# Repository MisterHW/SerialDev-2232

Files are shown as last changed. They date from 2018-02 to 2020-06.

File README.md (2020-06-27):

## SerialDev-2232 ##
The SerialDev-2232 board is a 50 x 50 mm² prototyping PCB with a FTDI FT2232HQ USB interface IC, 12 MHz oscillator and 3.3V, 1.2V LDOs. 

It breaks out the two Multi-Protocol Synchronous Serial Engine (MPSSE) ports, one particularly labeled as a JTAG / SPI / UART port, the other one as a full 16 I/O interface including the 8 bit parallel 245 type FIFO / bit banging interface.

Half of the PCB is dedicated to 5V, 3.3V, 1.2V supplies, 12 MHz clock source and a fully implemented FT2232H with EEPROM, all of which also feed into a linear header (cut the PCB in half for breadboard depolyment). The rest is just 0.1" perf board. 

### assembled PCB ###
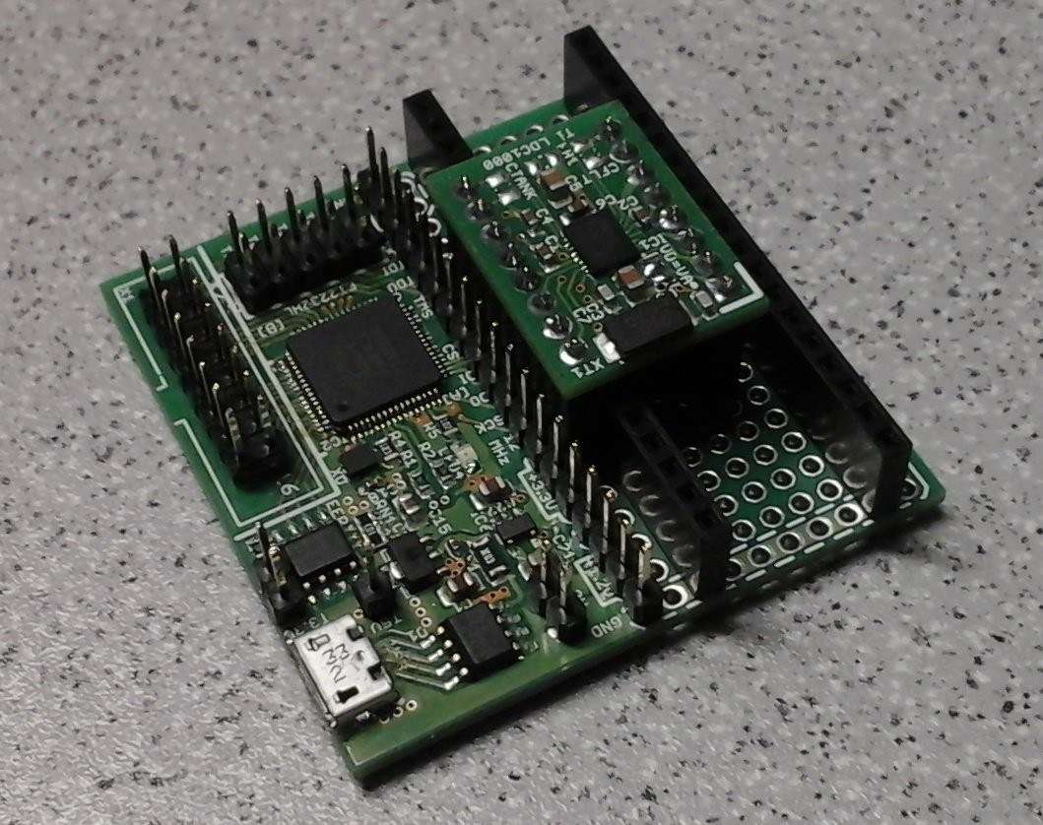
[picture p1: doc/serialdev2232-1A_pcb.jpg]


### schematic ###

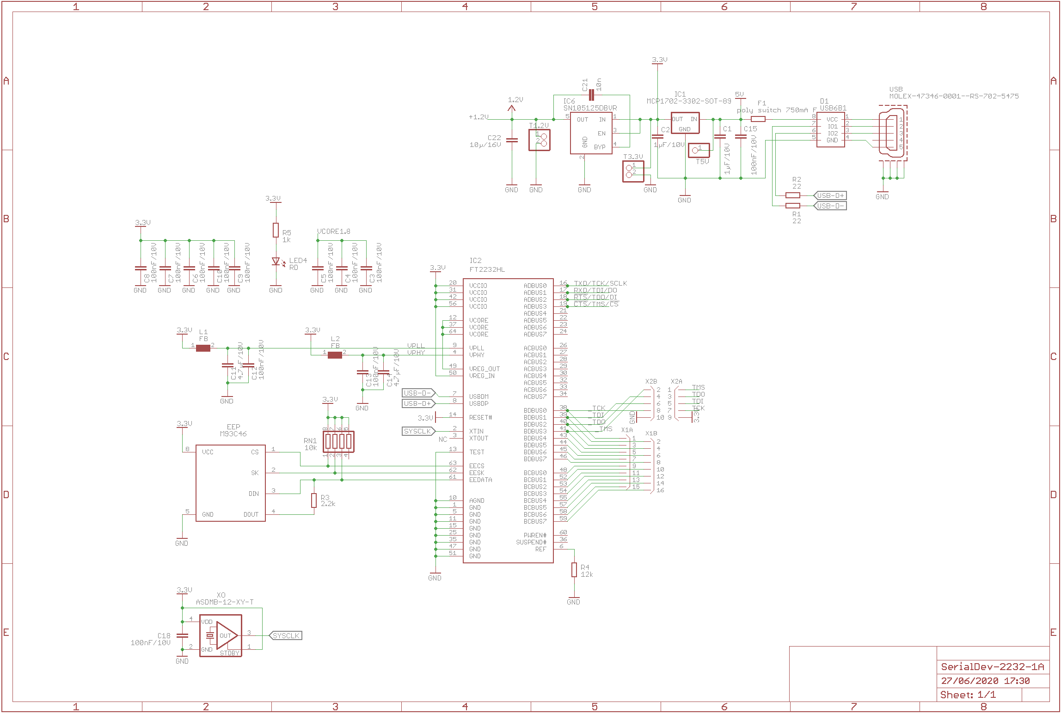
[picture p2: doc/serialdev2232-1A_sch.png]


### layout ###

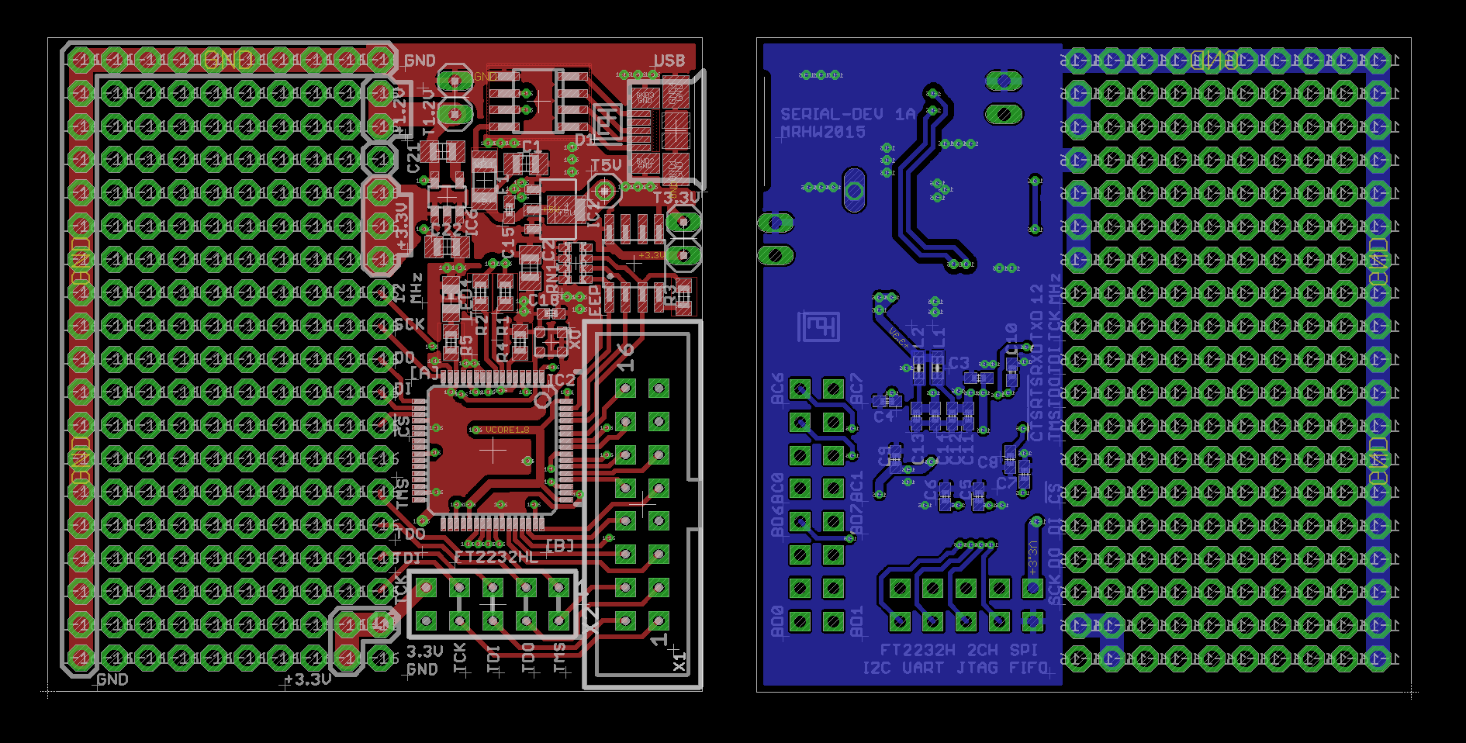
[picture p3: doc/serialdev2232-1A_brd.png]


### further information ###

For more please also check out https://hackaday.io/project/9902-serial-dev-2232.

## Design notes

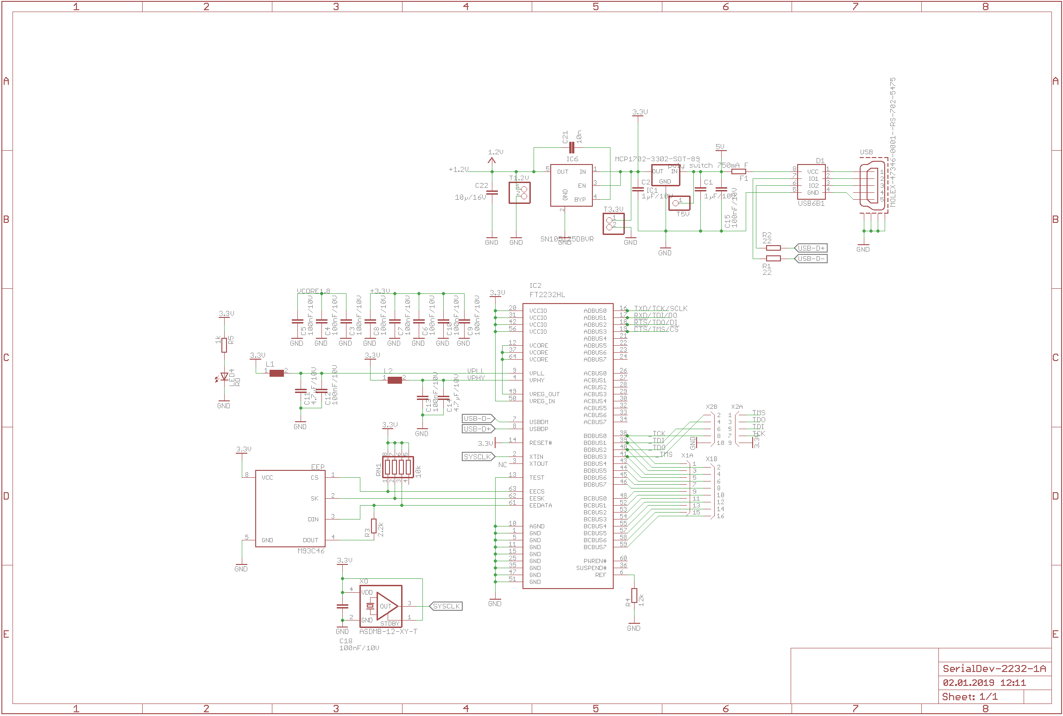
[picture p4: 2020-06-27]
doc/2232-schematic.png

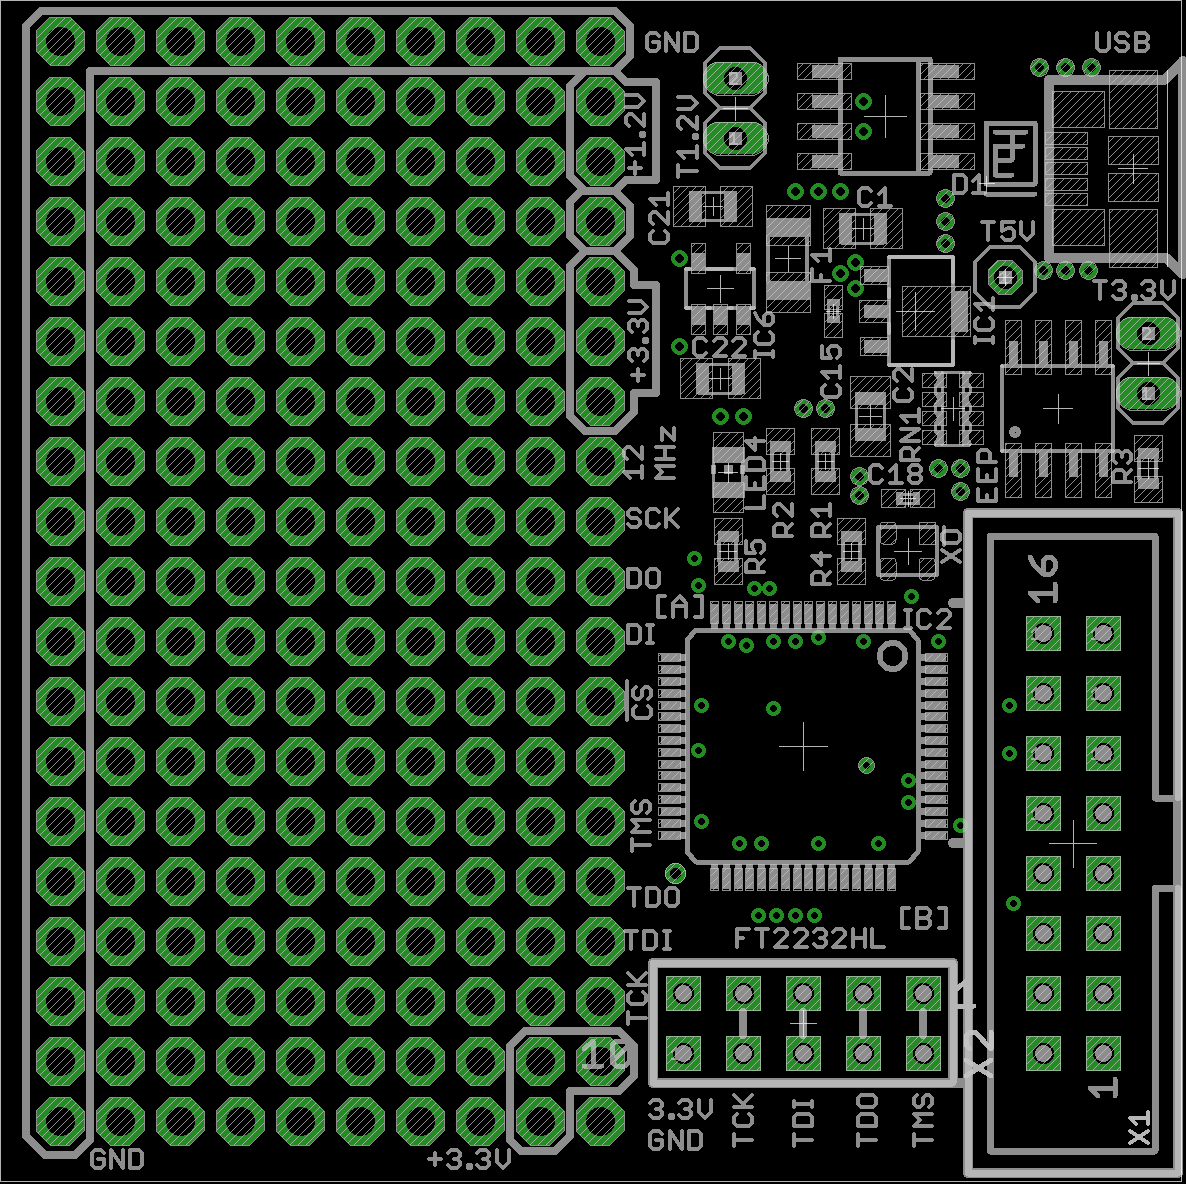
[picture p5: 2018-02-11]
doc/2232-top-silk.png

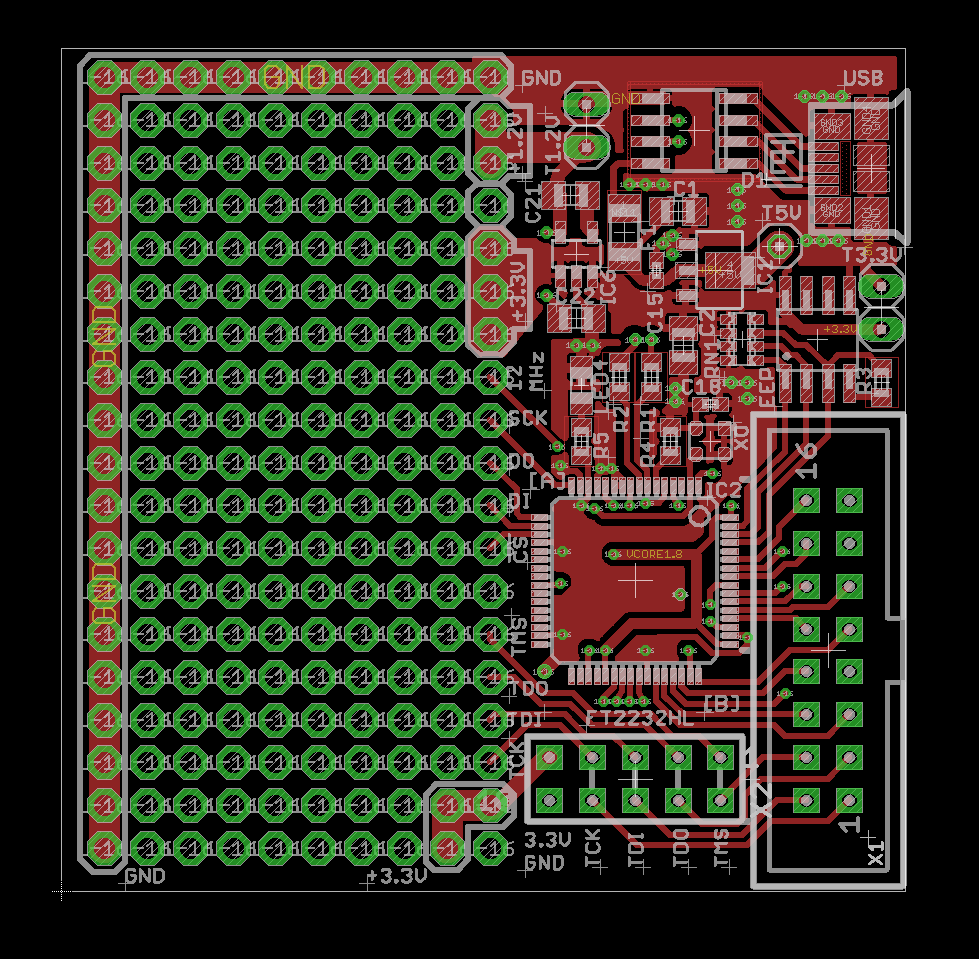
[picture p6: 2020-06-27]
doc/serialdev2232-1A_brd_top.png

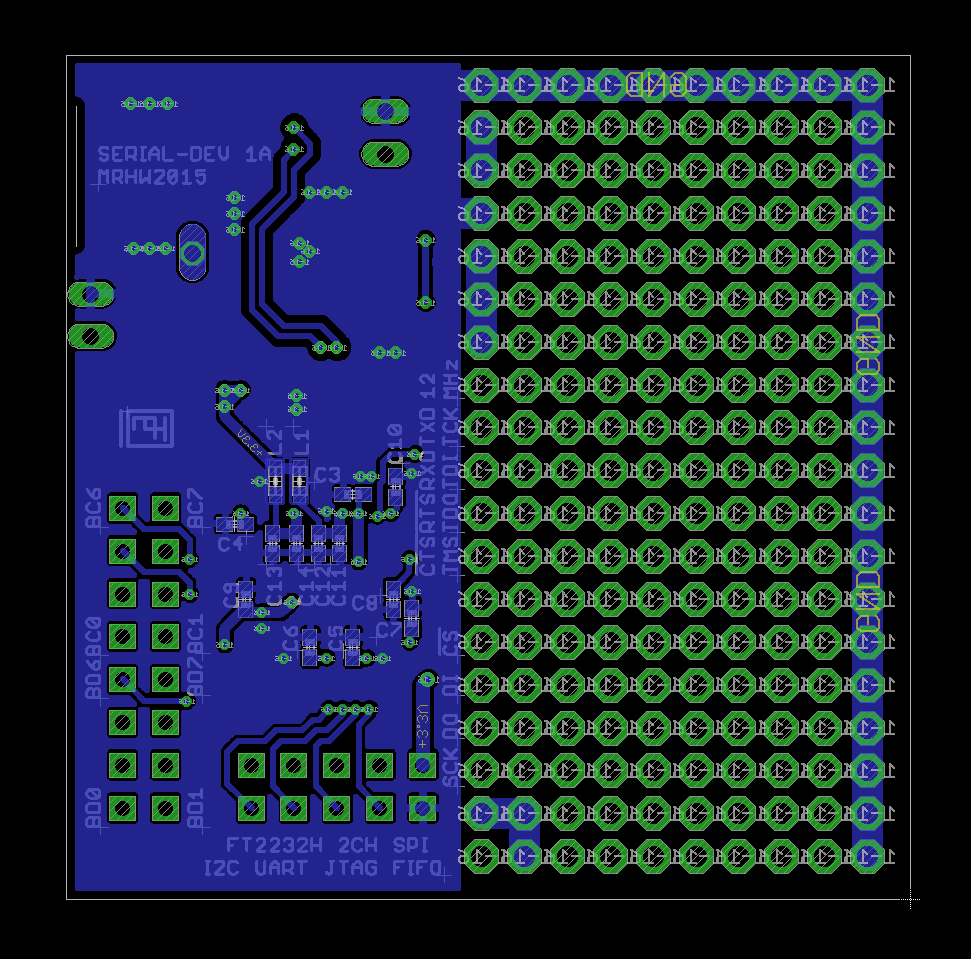
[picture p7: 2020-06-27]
doc/serialdev2232-1A_brd_btm.png

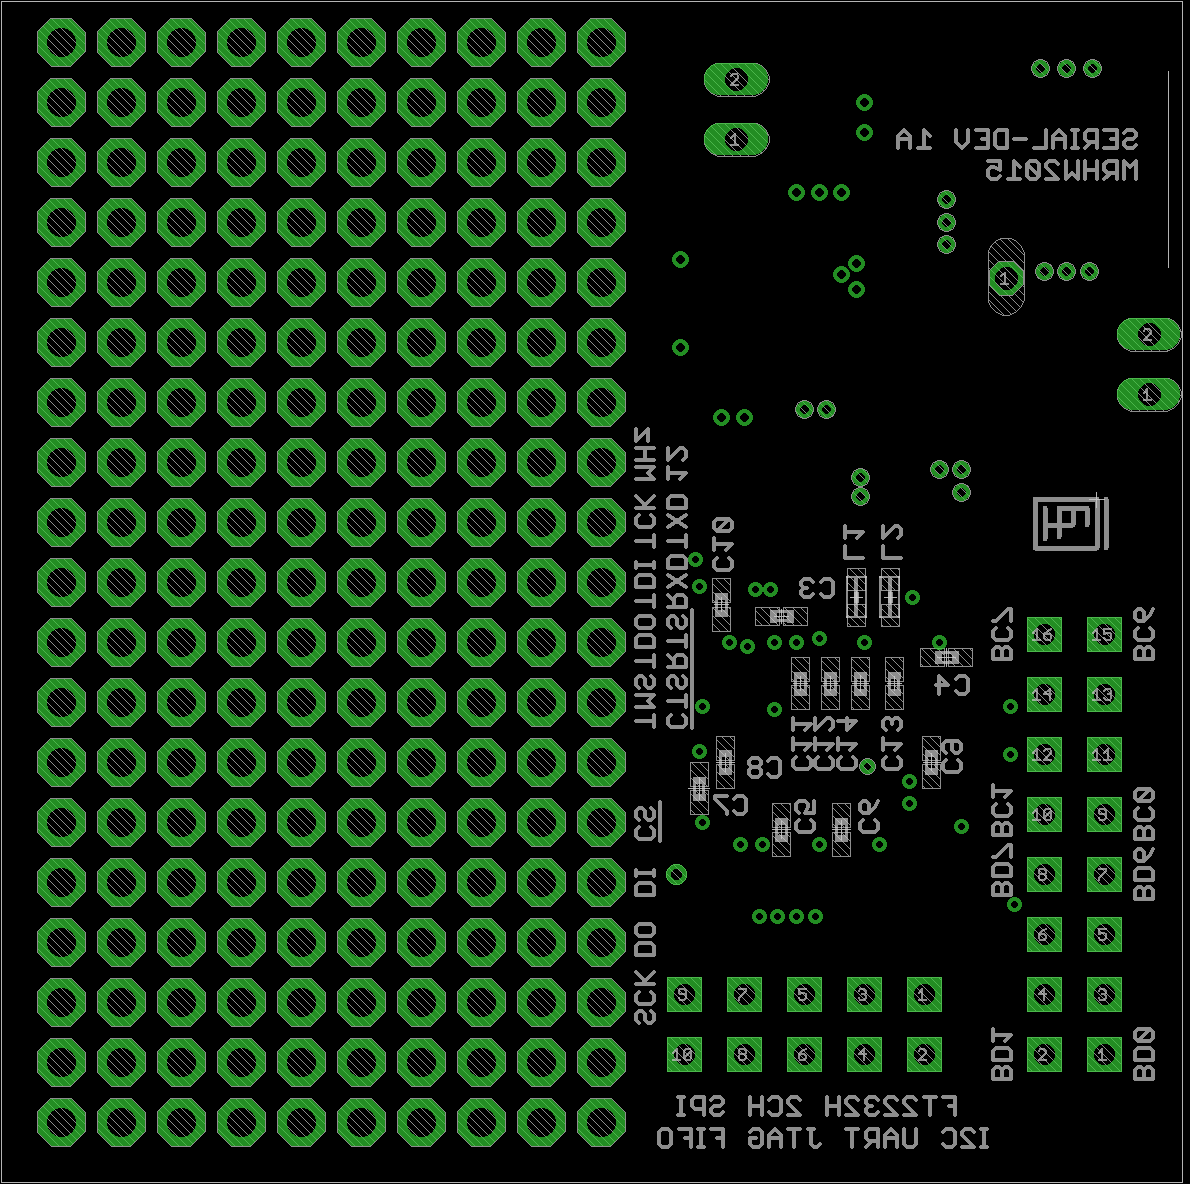
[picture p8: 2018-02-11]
doc/2232-btm-silk.png

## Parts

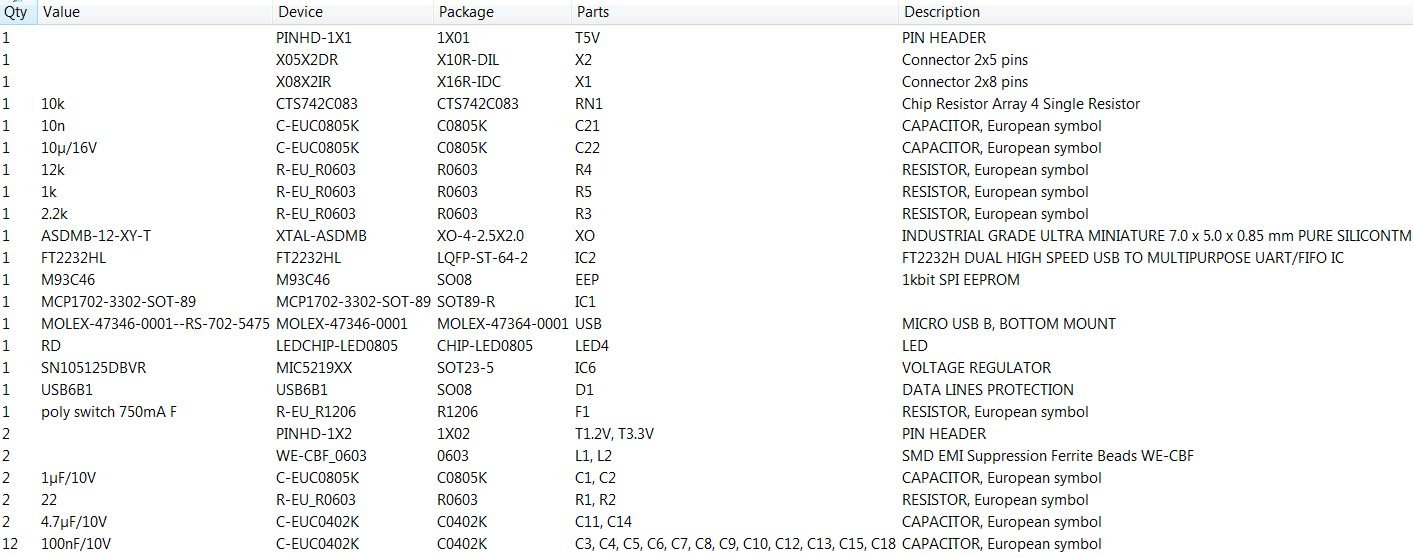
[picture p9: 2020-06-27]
doc/BOM.png

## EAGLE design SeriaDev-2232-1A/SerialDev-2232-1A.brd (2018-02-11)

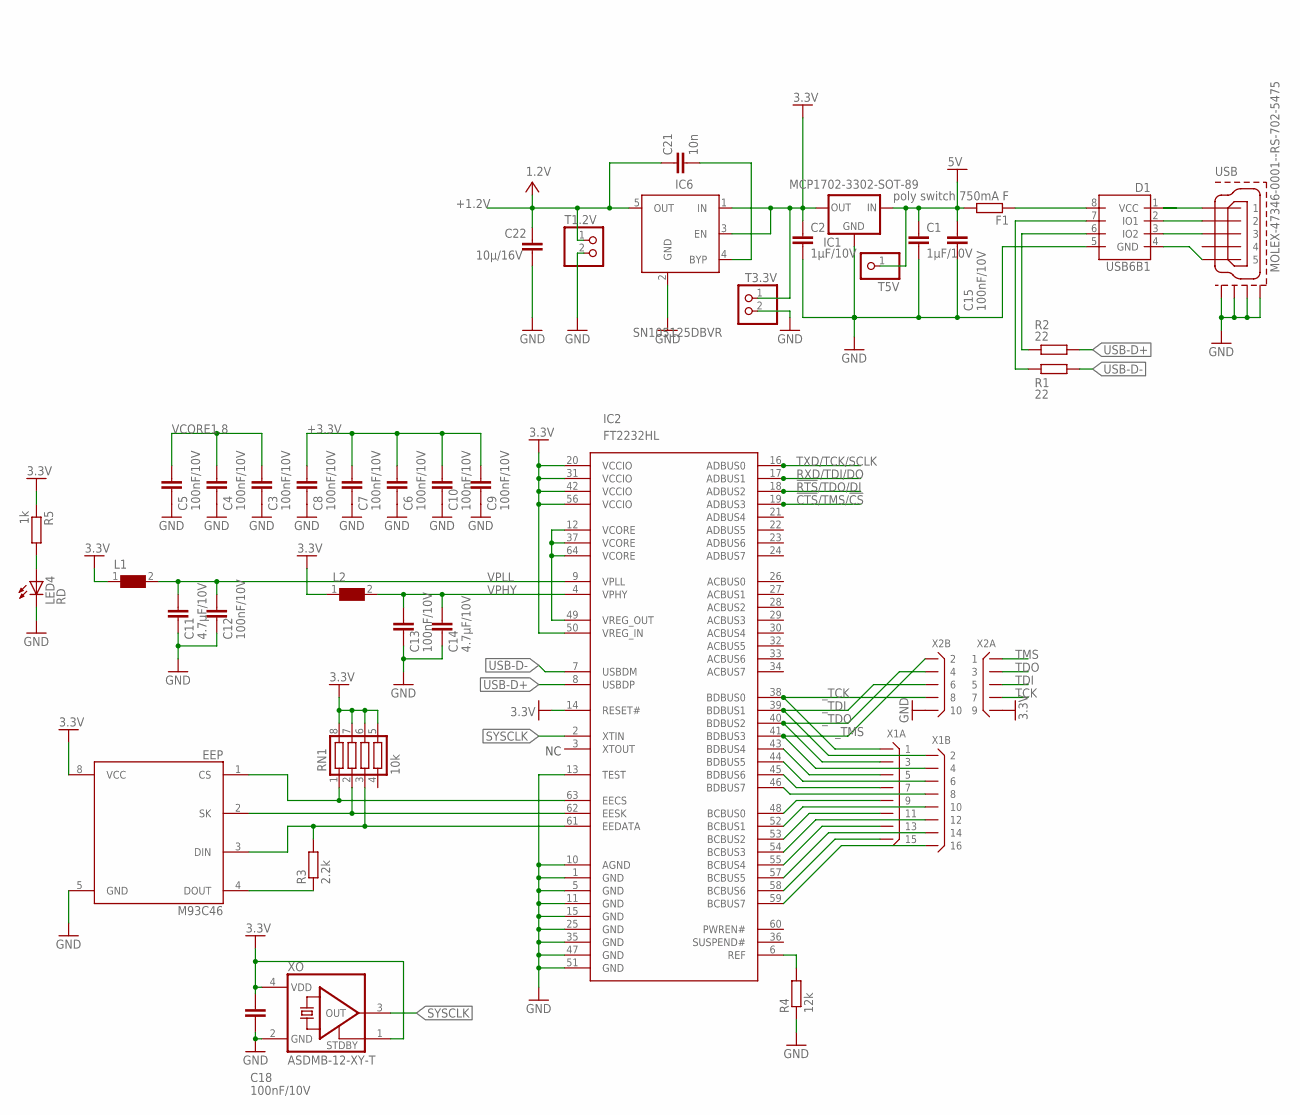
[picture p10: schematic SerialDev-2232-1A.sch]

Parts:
C1, C2: 1µF/10V; C0805K
C3, C4, C5, C6, C7, C8, C9, C10, C12, C13, C15, C18: 100nF/10V; C0402K; MOUSER 810-C1005X7R1H104K
C11, C14: 4.7µF/10V; C0402K; MOUSER 810-C1005X7R1H104K
C21: 10n; C0805K; PARTNO Kemet: C1206C103K5RACTU
C22: 10µ/16V; C0805K; PARTNO Vishay Sprague: TR3B106K016C0800
D1: USB6B1; SO08
EEP: M93C46; SO08
F1: poly switch 750mA F; R1206
IC1: MCP1702-3302-SOT-89; SOT89-R
IC2: FT2232HL; LQFP-ST-64-2
IC6: SN105125DBVR; SOT23-5; PARTNO LINEAR TECHNOLOGY: LT1761ES5-1.2
L1, L2: WE-CBF_0603; 0603
LED4: RD; CHIP-LED0805
R1, R2: 22; R0603
R3: 2.2k; R0603
R4: 12k; R0603
R5: 1k; R0603
RN1: 10k; CTS742C083
T1.2V, T3.3V: PINHD-1X2; 1X02
T5V: PINHD-1X1; 1X01
USB: MOLEX-47346-0001--RS-702-5475; MOLEX-47364-0001
X1: X08X2IR; X16R-IDC
X2: X05X2DR; X10R-DIL
XO: ASDMB-12-XY-T; XO-4-2.5X2.0; MFG_PARTNO ASDMB-12.000MHZ-XY-T; MOUSER 815-ASDMB-12-XY-T

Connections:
!CTS!/TMS/!CS!: IC2.19 (ADBUS3)
!RTS!/TDO/DI: IC2.18 (ADBUS2)
+1.2V: C21.1, C22.1, IC6.5 (OUT), T1.2V.1
+3.3V: C2.1, C6.1, C7.1, C8.1, C9.1, C10.1, C18.1, EEP.8 (VCC), IC1.3 (OUT), IC2.14 (RESET#), IC2.20 (VCCIO), IC2.31 (VCCIO), IC2.42 (VCCIO), IC2.50 (VREG_IN), IC2.56 (VCCIO), IC6.1 (IN), IC6.3 (EN), L1.1, L2.1, R5.1, RN1.5, RN1.6, RN1.7, RN1.8, T3.3V.1, X2.9, XO.1 (TRI), XO.4 (VDD)
+5V: C1.1, C15.1, F1.2, IC1.2 (IN), IC1.4 (IN), T5V.1
GND: C1.2, C2.2, C3.2, C4.2, C5.2, C6.2, C7.2, C8.2, C9.2, C10.2, C11.2, C12.2, C13.2, C14.2, C15.2, C18.2, C22.2, D1.5 (GND), EEP.5 (GND), IC1.1 (GND), IC2.1 (GND), IC2.5 (GND), IC2.10 (AGND), IC2.11 (GND), IC2.13 (TEST), IC2.15 (GND), IC2.25 (GND), IC2.35 (GND), IC2.47 (GND), IC2.51 (GND), IC6.2 (GND), LED4.C, R4.1, T1.2V.2, T3.3V.2, USB.GND1, USB.GND2, USB.GND3, USB.GND4, X2.10, XO.2 (GND)
unnamed: EEP.1 (CS), IC2.63 (EECS), RN1.1
unnamed: D1.6 (IO2), R2.1
unnamed: D1.7 (IO1), R1.2
unnamed: EEP.2 (SK), IC2.62 (EESK), RN1.2
unnamed: EEP.3 (DIN), IC2.61 (EEDATA), R3.2, RN1.3
unnamed: EEP.4 (DOUT), R3.1
unnamed: D1.4 (GND), USB.5
unnamed: D1.3 (IO2), USB.3
unnamed: IC2.6 (REF), R4.2
unnamed: D1.2 (IO1), USB.2
unnamed: D1.8 (VCC), F1.1
unnamed: C21.2, IC6.4 (BYP)
unnamed: LED4.A, R5.2
unnamed: IC2.43 (BDBUS4), X1.5
unnamed: IC2.44 (BDBUS5), X1.6
unnamed: IC2.45 (BDBUS6), X1.7
unnamed: IC2.46 (BDBUS7), X1.8
unnamed: IC2.48 (BCBUS0), X1.9
unnamed: IC2.52 (BCBUS1), X1.10
unnamed: IC2.53 (BCBUS2), X1.11
unnamed: IC2.54 (BCBUS3), X1.12
unnamed: IC2.55 (BCBUS4), X1.13
unnamed: IC2.57 (BCBUS5), X1.14
unnamed: IC2.58 (BCBUS6), X1.15
unnamed: IC2.59 (BCBUS7), X1.16
RXD/TDI/DO: IC2.17 (ADBUS1)
SYSCLK: IC2.2 (XTIN), XO.3 (OUT)
TCK: X2.7
TDI: X2.5
TDO: X2.3
TMS: X2.1
TXD/TCK/SCLK: IC2.16 (ADBUS0)
USB-D+: IC2.8 (USBDP), R2.2
USB-D-: IC2.7 (USBDM), R1.1
USB_5V: D1.1 (VCC), USB.1
VCORE1.8: C3.1, C4.1, C5.1, IC2.12 (VCORE), IC2.37 (VCORE), IC2.49 (VREG_OUT), IC2.64 (VCORE)
VPHY: C13.1, C14.1, IC2.4 (VPHY), L2.2
VPLL: C11.1, C12.1, IC2.9 (VPLL), L1.2
_TCK: IC2.38 (BDBUS0), X1.1, X2.8
_TDI: IC2.39 (BDBUS1), X1.2, X2.6
_TDO: IC2.40 (BDBUS2), X1.3, X2.4
_TMS: IC2.41 (BDBUS3), X1.4, X2.2

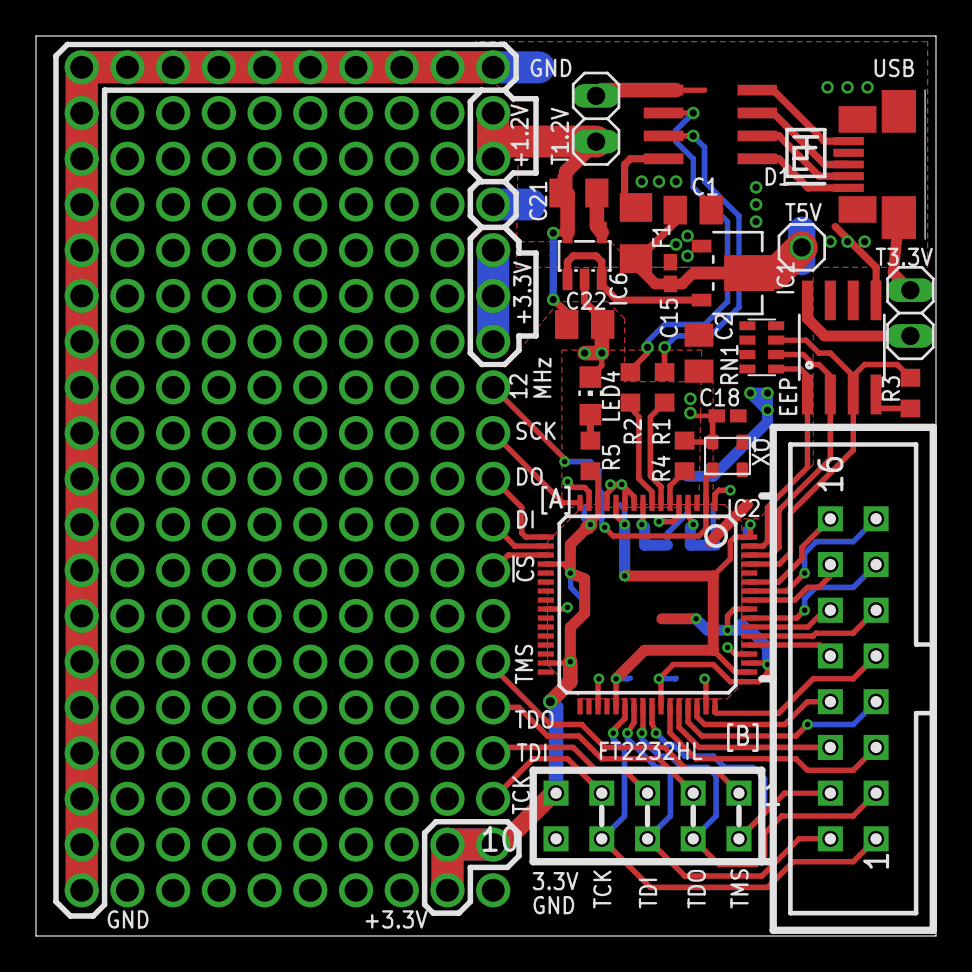
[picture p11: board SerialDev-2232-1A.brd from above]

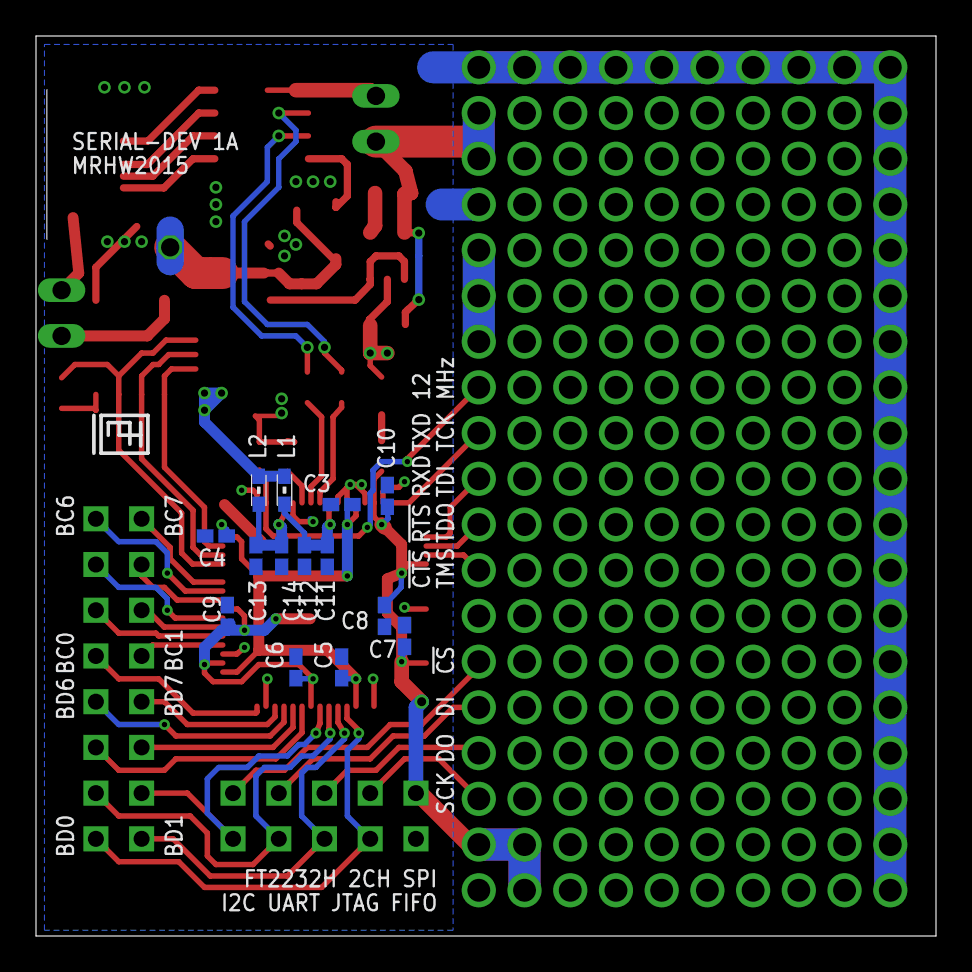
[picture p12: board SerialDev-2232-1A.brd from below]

Board: 2 copper layers, 50.0 x 50.0 mm, 42 parts (15 on the bottom side), 40 nets.

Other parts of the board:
U$1, U$2: DESIGNER

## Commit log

2018-02-11 initial commit of hardware iteration 1A (built and tested, seems ok)
    [SerialDev-2232-1A.brd, SerialDev-2232-1A.sch]
2018-02-11 Create README.md
    The SerialDev-2232 board is a 50 x 50 mm² PCB that breaks out the two MPSSE ports, one as a JTAG / SPI / UART port, the other one as a fully featured MPSSE interface including the 8 bit parallel 245 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
    Half of the PCB is dedicated to 5V, 3.3V, 1.2V supplies, 12 MHz clock source and a fully implemented FT2232H with EEPROM, all of which also feed into a linear header (cut the PCB in half for breadboa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
    for more please also check out https://hackaday.io/project/9902-serial-dev-2232
2019-01-02 add schematic png
2020-06-27 remove duplicate doc/, add gerber files.
2020-06-27 added BOM

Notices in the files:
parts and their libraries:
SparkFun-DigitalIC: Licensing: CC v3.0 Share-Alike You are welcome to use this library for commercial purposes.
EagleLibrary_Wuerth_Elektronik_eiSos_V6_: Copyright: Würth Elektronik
